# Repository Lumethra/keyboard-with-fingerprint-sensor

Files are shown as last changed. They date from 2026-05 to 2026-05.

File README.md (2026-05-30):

# Auth 75

## What is this? 

This is a 75% keyboard with a fingerprint sensor. What? A fingerprint sensor in a keyboard? Yes, you've heard it right! This keyboard includes a working fingerprint sensor. But how does it work? Aren't fingerprint sensors tied to motherboards? Continue reading, to get an answer to this question. 

### Features: 
  - Keycool84 layout (modified)
  - Raspberry Pi Pico 2W
    - ZMK (not tested)
    - LiPo battery
    - Battery charger
  - Rotary Encoder Switch (EC11)
  - USB Hub (SL2.1)
    - 1 USB-C upstream
    - 2 USB-C downstreams
    - 1 notched FPC-connector (fingerprint sensor)
    - 1 USB-C to connect to the Pico

---

## Why? 

I always wanted a good keyboard with a working fingerprint sensor, because my password is always too long and I am used to the one on my laptop. Why not just use the one on my laptop? Because I want to close my laptop lid while using a monitor. The second reason is that the one on my laptop doesnt work on Linux, so I wanted to make compatible with my main OS. 

---

## How? 

I did some research and found out that the Framework 13 Fingerprint Reader isnt tied to their motherboard, unlike Lenovo or Dell. I also found a [Framework-Community-Post](https://community.frame.work/t/framework-fingerprint-scanner-for-a-desktop-pc/29845), where the people managed to use the sensor via USB-C. They also found out that the D+ and D- pins are inverted. A huge thank you to these guys. After buying the sensor and testing its functionalty at home, I decided on using a USB-Hub to have the fingerprint reader and the keyboard MCU in on connector. Frameworks support also helped me out with the fingerprint sensor datasheet. And now I've got a 75% keyboard with a working fingerprint sensor. 

---

## Renders

| PCB with Components | 
| --- |
| Auth75 Front with Components |
| Auth75 Back with Components |

| PCB without Components |
| --- |
| Auth75 Front without Components |
| Auth75 Back without Compoenents |

| Case |
| --- |
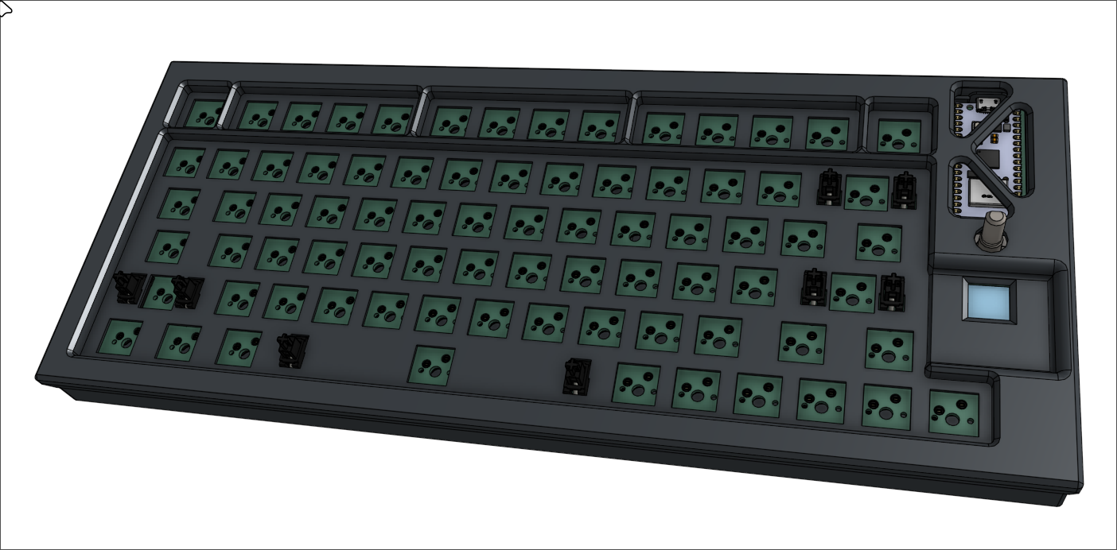
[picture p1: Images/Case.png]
Auth75 Case
|  |
| Thank you Chroma for making this wonderful case |
| The case source files are [here](https://cad.onshape.com/documents/94c98908253eab7c65b6f4cc/w/cb3c129046b9b5460a1f53f5/e/8f22757c89f8236cf1eb1f99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) |

---

## PCB + Schematics

| Schematics |
| --- |
| Auth75-PCB |

| PCB |
| --- |
| Auth75-Schematics |

---
<details>
  <summary>
    <h2>Zine</h2> 
  </summary>

| Zine |
| --- |
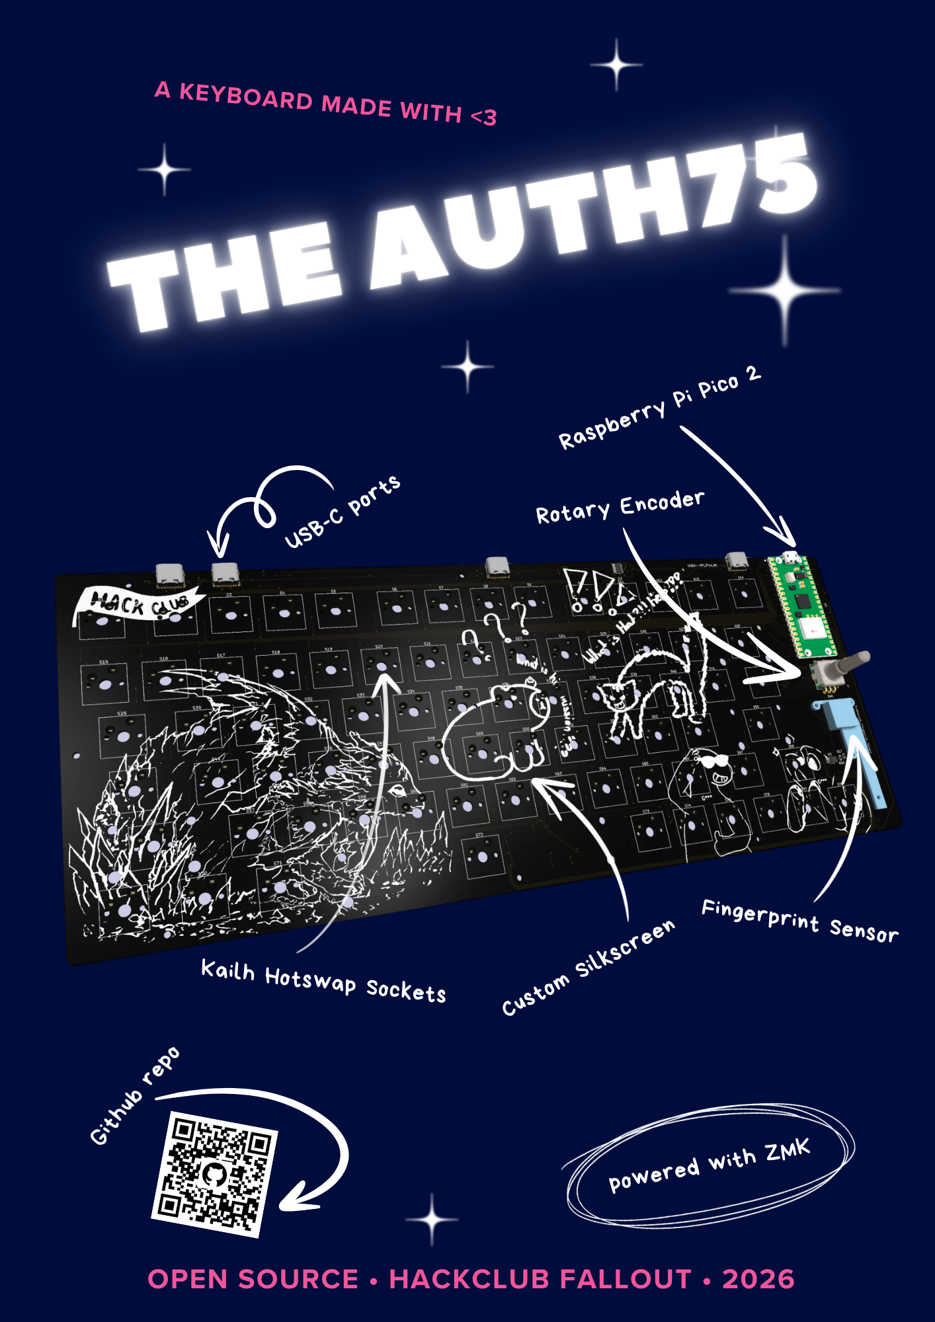
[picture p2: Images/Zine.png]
Auth75-Zine
|  |

---
</details>

## BOM

| Part | Purpose | Cost | Quantity | Total Cost | LCSC/JLCPCB Number | Link |
| --- | --- | --- | --- | --- | --- | --- |
| PCB | connecting every component | ~ | 1 (5) | $22.60 | ~ | [JLCPCB](https://jlcpcb.com/) |
| Pico 2W | main MCU (handeling software) | ~$7 | 1 | $7 | C42394205 (JLCPCB) | [Raspberry Pi](https://www.raspberrypi.com/products/raspberry-pi-pico-2/) |
| Kailh Hotswap Sockets | holding the switches to the PCB without soldering | $0.1183 | 78 | ~$9 | C2803348 | [JLCPCB](https://jlcpcb.com/partdetail/C2803348) |
| Kailh (Cocoa) Switches | the switches you can press | $0 (comes with a Rainy75) | 78 | $0 (already owned) | ~ | ~ |
| Keycaps | goes onto the switches for better look and feel | $0 (3d printing ABS) | 78 | $0 (3d printed) | ~ | ~ |
| EC11 Rotary Encoder Switch | goes uii and click click | $2.22 | 1 | $2.22 | C370970 | [JLCPCB](https://jlcpcb.com/partdetail/C370970) / [Amazon](https://www.amazon.de/-/en/RUNCCI-YUN-Potentiometer-Automotive-Electronics-Multimedia/dp/B09SG3HF9N) |
| Fingerprint Reader Kit | recognize your finger | $29.00 | 1 | $29.00 | ~ | [Framework](https://frame.work/products/fingerprint-reader-kit?v=FRANTD0001) |
| KYOCERA AVX FPC Connector | connect the fingerprint sensor | $0.3775 | 1 | $0.3775 | C5464531 | [JLCPCB](https://jlcpcb.com/partdetail/C5464531) |
| USB-C connector | connect to laptop | $0.0740 | 4 | $0.296 | C2765186 | [JLCPCB](https://jlcpcb.com/partdetail/C2765186) |
| PCA9536DGKR | I2C GPIO expander (more GPIO pins, yeeee) | $1.2053 | 1 | $1.2053 | C2649389 | [JLCPCB](https://jlcpcb.com/partdetail/C2649389) |
| SL2.1s | USB Hub core component | $0.2258 | 1 | $0.2258 | C2684433 | [JLCPCB](https://jlcpcb.com/partdetail/C2684433) |
| MMBT3904 | letting the Pi control the LEDs on the sensor | $0.0095 | 3 | $0.0285 | C20526 | [JLCPCB](https://jlcpcb.com/partdetail/C20526) |
| SS8550 Y2 | implementing the sensor switch into the matrix | $0.0134 | 1 | $0.0134 | C8542 | [JLCPCB](https://jlcpcb.com/partdetail/C8542) |
| MCP73831T-2ACI/OT | battery charger | $0.7585 | 1 | $0.7585 | C424093 | [JLCPCB](https://jlcpcb.com/partdetail/C424093) |
| DW01A | battery protector | $0.0426 | 1 | $0.0426 | C351410 | [JLCPCB](https://jlcpcb.com/partdetail/C351410) |
| FS8205A | mosfet for protector | $0.0470 | 1 | $0.0470 | C2830320 | [JLCPCB](https://jlcpcb.com/partdetail/C2830320) |
| S2B-PH-SM4-TB | connector for battery | $0.2014 | 1 | $0.2014 | C295747 | [JLCPCB](https://jlcpcb.com/partdetail/C295747) |
| Resistors | prevent things go boom | ~$0.0016 | 19 | ~$0.0304 | C23186, C21190, C22775, C23162 | [C23186](https://jlcpcb.com/partdetail/C23186) / [C21190](https://jlcpcb.com/partdetail/C21190) / [C22775](https://jlcpcb.com/partdetail/C22775) / [C23162](https://jlcpcb.com/partdetail/C23162) |
| Diodes | prevent voltage from backflowing | $0.0117 | 82 | ~$0.9594 | C81598 | [JLCPCB](https://jlcpcb.com/partdetail/C81598) |
| Capacitors | smooth out the power | $0.0032 - $0.0110 | 14 | ~$0.0956 | C15849, C19666, C14663 | [C15849](https://jlcpcb.com/partdetail/C15849) / [C19666](https://jlcpcb.com/partdetail/C19666) / [C14663](https://jlcpcb.com/partdetail/C14663) |

> the prices can vary depending on the provider <br>
> you can find the JLCPCB parts on [LCSC](https://lcsc.com/) too (exept the PCB and the Pico) <br>
> note: u could solder a pico 2 on there instead, cause its physically the same

---

## Contribute

Want to make it better? Found some bugs? Feel free to open a PR (pull request) and lets make the project better. ^_^
> the libraries are all imported with [easyeda2kicad](https://github.com/uPesy/easyeda2kicad.py) and [kiswitch](https://github.com/kiswitch/kiswitch)

---

## Thank you

A huge thank you to all these guys helping me out with my project. <br>
[@eggsplats](https://github.com/geg-tech), [@Kai Pereira](https://github.com/KaiPereira), [@Aadit Bhambri](https://github.com/abinnovator), [@technical_.](https://github.com/techn1-cal) and [@Tanuki](https://github.com/TaniWanKenobi) for helping out on my way and inspiring me with their passion and projects. <br>
Another thank you to my sister (for **some** of the art), the Framework support (for the datasheet of the sensor), the guys in the [Framework-Community-Post](https://community.frame.work/t/framework-fingerprint-scanner-for-a-desktop-pc/29845) (for the functionality of the sensor), my [friend](https://github.com/Chroma165) (for the case and 3d model of the fingerprint sensor) and my [other friend](https://github.com/Leonhoch5) (for the emotional support)
> Thank you guys <3

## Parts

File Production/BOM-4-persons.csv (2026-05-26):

Part | Purpose | Cost | Quantity | Total Cost | LCSC/JLCPCB Number | Purchase Link
PCB | connecting every component | ~ | 1 (5) | $22.60 | ~ | https://jlcpcb.com/
Pico 2W | main MCU (handeling software) | ~$7 | 1 | $7 | C42394205 | https://www.raspberrypi.com/products/raspberry-pi-pico-2/
Kailh Hotswap Sockets | holding the switches to the PCB without soldering | $0.1183 | 78 | ~$9 | C2803348 | https://jlcpcb.com/partdetail/C2803348
Kailh (Cocoa) Switches | the switches you can press | $0 (comes with a Rainy75) | 78 | $0 (already owned) | ~ | ~
Keycaps | goes onto the switches for better look and feel | $0 (3d printing ABS) | 78 | $0 (3d printed) | ~ | ~
EC11 Rotary Encoder Switch | goes uii and click click | $2.22 | 1 | $2.22 | C370970 | https://jlcpcb.com/partdetail/C370970
Fingerprint Reader Kit | recognize your finger | $29.00 | 1 | $29.00 | ~ | https://frame.work/products/fingerprint-reader-kit?v=FRANTD0001
KYOCERA AVX FPC Connector | connect the fingerprint sensor | $0.3775 | 1 | $0.3775 | C5464531 | https://jlcpcb.com/partdetail/C5464531
USB-C connector | connect to laptop | $0.0740 | 4 | $0.296 | C2765186 | https://jlcpcb.com/partdetail/C2765186
PCA9536DGKR | I2C GPIO expander (more GPIO pins yeeee) | $1.2053 | 1 | $1.2053 | C2649389 | https://jlcpcb.com/partdetail/C2649389
SL2.1s | USB Hub core component | $0.2258 | 1 | $0.2258 | C2684433 | https://jlcpcb.com/partdetail/C2684433
MMBT3904 | letting the Pi control the LEDs on the sensor | $0.0095 | 3 | $0.0285 | C20526 | https://jlcpcb.com/partdetail/C20526
SS8550 Y2 | implementing the sensor switch into the matrix | $0.0134 | 1 | $0.0134 | C8542 | https://jlcpcb.com/partdetail/C8542
MCP73831T-2ACI/OT | battery charger | $0.7585 | 1 | $0.7585 | C424093 | https://jlcpcb.com/partdetail/C424093
DW01A | battery protector | $0.0426 | 1 | $0.0426 | C351410 | https://jlcpcb.com/partdetail/C351410
FS8205A | mosfet for protector | $0.0470 | 1 | $0.0470 | C2830320 | https://jlcpcb.com/partdetail/C2830320
S2B-PH-SM4-TB | connector for battery | $0.2014 | 1 | $0.2014 | C295747 | https://jlcpcb.com/partdetail/C295747
Resistors 5.1k | prevent things go boom | $0.0016 | 10 | ~$0.016 | C23186 | https://jlcpcb.com/partdetail/C23186
Resistors 1k | prevent things go boom | $0.0016 | 6 | ~$0.0096 | C21190 | https://jlcpcb.com/partdetail/C21190
Resistors 100 | prevent things go boom | $0.0016 | 1 | ~$0.0016 | C22775 | https://jlcpcb.com/partdetail/C22775
Resistors 4.7k | prevent things go boom | $0.0016 | 2 | ~$0.0032 | C23162 | https://jlcpcb.com/partdetail/C23162
Diodes | prevent voltage from backflowing | $0.0117 | 82 | ~$0.9594 | C81598 | https://jlcpcb.com/partdetail/C81598
Capacitors 1uF | smooth out the power | $0.0032 | 8 | ~$0.0256 | C15849 | https://jlcpcb.com/partdetail/C15849
Capacitors 4.7uF | smooth out the power | $0.0110 | 2 | ~$0.022 | C19666 | https://jlcpcb.com/partdetail/C19666
Capacitors 100nF | smooth out the power | $0.0032 | 4 | ~$0.0128 | C14663 | https://jlcpcb.com/partdetail/C14663

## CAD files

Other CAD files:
CAD/Case/Auth75-SwitchPlate.step
CAD/PCB/keyboard-PCB.step
CAD/Case/Auth75-TopHalf.step
CAD/Case/Auth75-bottomHalf.step

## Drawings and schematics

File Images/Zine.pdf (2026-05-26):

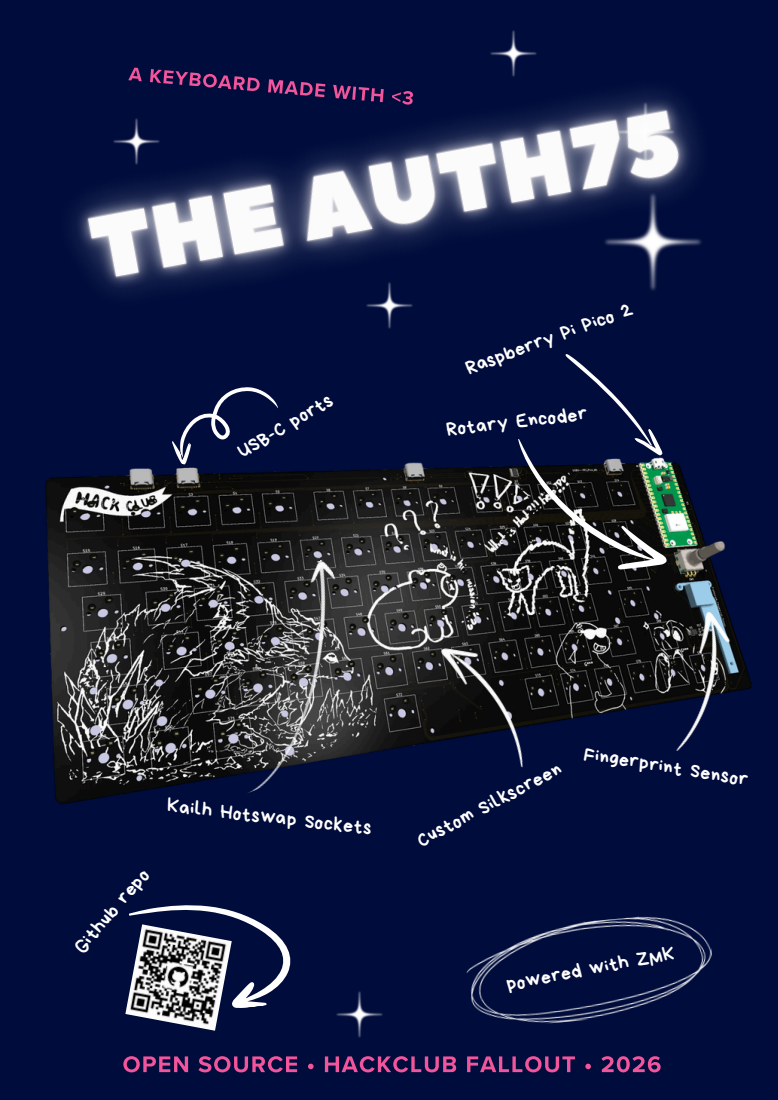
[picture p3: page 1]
Fingerprint Sensor; Custom Silkscreen; THE AUTH75; Rotary Encoder; USB-C ports; Github repo

A KEYBOARD MADE WITH <3

Raspberry Pi Pico 2

Kailh Hotswap Sockets

powered with ZMK

OPEN SOURCE • HACKCLUB FALLOUT • 2026

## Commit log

2026-05-18 rename to Auth75
    [Auth75.kicad_sch, keyboard-with-fingerprint-sensor.kicad_sch]
2026-05-22 generating new CAD
    [Auth75.kicad_sch, keyboard-PCB.step]
2026-05-23 optimizing for PCBA, so it does cost too much, especially the 'Feeders loading Fee'
    [Auth75.kicad_sch, bom.csv, designators.csv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]
2026-05-24 changing page size and getting sanity checks by @abtheinnovator
    [Auth75.kicad_sch]
2026-05-24 changing page size and getting sanity checks by @abtheinnovator and fixing silkscreen that got fcked up
    [Auth75.kicad_sch]
2026-05-24 regenerating CAD in lower res
    [keyboard-PCB.step]
2026-05-24 starting the BOM and finishing first paragraph in README
2026-05-26 adding BOM-4-persons, hope fallout check goes through now
    [BOM-4-persons.csv]
2026-05-26 still not working, trying swapping
    [BOM-4-persons.csv, bom-2-upload.csv, bom.csv]
2026-05-27 case stuff
    [Auth75-SwitchPlate.step, Auth75-TopHalf.step, Auth75-bottomHalf.step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]
2026-05-30 Fix image source case in README.md
